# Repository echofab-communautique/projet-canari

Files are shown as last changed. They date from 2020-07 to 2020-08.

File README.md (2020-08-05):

# projet-canari
captation citoyenne de données sur la qualité de l’air

canari

_Les bien commun de l’environnement_  
Communautique, en tant qu’organisme de démocratisation des technologies, souhaite créer un espace de conversation sur les données ouvertes, les capteurs et leurs usages. Le Projet Canari vise à développer des contenus de formation pratiques de création et d’appropriation des données locales pour la résolution d’enjeux urbains, comme la qualité de l’air.  

(http://www.youtube.com/watch?v=Zew5YFMf60w "Click to see our trailer")

## Le processus en bref:  
Utiliser les Fab Labs (espaces citoyens) pour prendre actions sur le changement climatique

1- Une marche de sensibilisation de son environnement  “Rendre l’invisible visible”  
2- Construction d’un outils permettant de capter par le citoyen  
  2.1- Introduction au fab lab et technologie de fabrication numérique  
3- Installation et captation (contribution ou création de data citoyenne)  
4- Retour et analyse des données captée  
5- Recherche de solutions  
6- Processus itératif en amélioration continue  

## Besoins  
La mobilisation des habitants sur les questions des capteurs, des données et de l’environnement (qualité de l’air) permettra de développer la littératie des données.
Le Projet Canari souhaite ainsi contribuer à :
* Développer la littératie des données
* Connecter le citoyen aux notions de changement climatique (rendre visible la dimension invisible des changements climatiques dans des ancrages locaux). Les changements climatiques ont trop souvent quelque chose d’abstrait, mais pour beaucoup de citoyens, avoir un air respirable dans notre ville est la priorité environnementale.
* Valoriser le savoir scientifique en recueillant les données par une méthodologie de recherche  

Afin d'accompagner les citoyen.nes dans leur démarche de captation, une escouade des données («data squad») - composée de personnes aux compétences complémentaires (techniques, anthropolo/ethnologique, communication/animation) - sera formée afin d'animer et de soutenir la participation au projet. Cette petite équipe terrain joue un rôle crucial de médiation «socio-technique» - en proximité avec les participant.e.s du projet : elle facilite l'appropriation de l'instrumentation, identifie des opportunités d'intervention, soutient les processus de collecte, d'analyse et d'interprétation des données. L'escouade est également responsable de la mutualisation des informations collectées (en respectant les cadres et les règles de confidentialité et de protection des renseignements personnels), dans la perspective de constitution d'un commun des données citoyennes sur l'environnement.  

Le temps de la data squad :  
* ils accompagnent le lancement du projet
* ils accompagnent la fabrication au Fab Lab des capteurs
* accompagnent hebdomadaire/ visite – formation des capteurs et accompagnement virtuel/ à travers la plateforme

Les habitants participants au projet s’engage:
* sur une période de deux mois via une charte d’engagement sur l'impératif de protection des données personnelles et de la législation
* à avoir à disposition un kit de mesure contenant un capteur de mesure de particules fines et de la documentation sur le sujet
* à évaluer son exposition personnelle aux particules fines présentes dans l'air qui nous entoure
* à réfléchir aux comportements que l'on peut adopter pour améliorer son air extérieur
* à se sensibiliser et sensibiliser les autres en en parlant autour de soi
* à participer à des animations avec des experts

## Mise en contexte, historique du projet
Nous assistons actuellement à une transformation profonde à l’échelle mondiale qui est alimentée par la technologie et les médias numériques, et stimulée par les données et les flux d’information. Cette transformation constitue un potentiel énorme pour renforcer la transparence, la redevabilité , l’efficience, l’agilité et l’efficacité des gouvernements ainsi que des organisations de la société civile et du secteur privé et pour appuyer la conception, la mise en œuvre et l’évaluation d’objectifs de développement durable à l’échelle mondiale. Les données ouvertes sont au cœur de ce mouvement mondial. Cependant, la formation à l’usage des données est un préalable essentiel et trop souvent négligé pour un usage plus large des données.

La création et l’usage de données ouvertes offrant un beau potentiel de s'approprier sa Ville, Communautique en tant qu’organisme de formation continue, engagé dans le mouvement mondial des Fab City, propose le Projet Canari. Articulant depuis maintenant plusieurs années des activités autour des laboratoires de fabrication numérique et la mise en place d’un réseau de fabrication numérique au Québec, le projet permettra de démontrer le rôle des Fab Labs :
* dans la gestion des compétences et des connaissances à l’échelle individuelle et collective
* comme espace de médiation entre les habitants et les enjeux de société
* à faciliter la participation citoyenne et la mise en place d’une communauté de pratique
* pour envisager la technologie comme outil pour façonner le territoire différemment
* pour favoriser le développement inclusif de solutions et l’innovation

Le canari sentinelle

“Au XIXe siècle, alors que l’exploitation des mines de charbon battait son plein, il était fréquent de retrouver, au fond des mines, un canari. Très sensible aux émanations de gaz toxiques, impossibles à détecter pour les hommes ne bénéficiant pas des équipements modernes, le petit oiseau jaune servait d’outil de référence. Ainsi, lorsqu’il mourait ou s’évanouissait, les mineurs se dépêchaient de sortir de la mine afin d’éviter une explosion ou une intoxication imminentes.” Source : Histoires oubliées http://www.histoiresoubliees.ca/article/la-mine-federale/les-canaris-dans-les-mines-de-charbon

## Objectif général
Le Projet Canari contribue à développer la littératie numérique et environnementale et à rendre les citoyens acteurs de la mesure de la qualité de l’air en les accompagnant à fabriquer des micro-capteurs.  
Par la formation aux enjeux de la production et de l’utilisation des données ouvertes, il outillera concrètement les citoyens, dont des nouveaux arrivants, en améliorant leurs compétences et connaissances pour utiliser l’Internet et les données de manière signifiante et sécuritaire.  

## Nomenclature (BOM)

[BOM.pdf](https://github.com/echofab-communautique/projet-canari/files/5006105/BOM.pdf)

Elements:
1x Jumper Cable
1x Cable USB
1x Arduino Nano
1x Ecran OLED
1x Senseur PM2.5
1x PCB
1x Résistance 150 Ohms
1x Cap 220 uF
2x Terminal Block 5mm / 3pos
2x Terminal Block 5mm / 2pos

Autres:
Fil à pêche (30cm)
Impressions 3D (coeur, set de press pin -bec & tail miroir) => voir dossier 1_3Dprint
Découpe laser du profil extérieur => voir dossier 3_Laser
Découpe vinyle des ailes => voir dossier 2_Vinyle
Tournevis

Pour plus de détails, vous pouvez télécharger et consulter le fichier BOM.pdf

## Réalisation  

Les fichiers de production sont téléchargeables dans les dossiers de ce projet:  
* 1_3Dprint  
* 2_Vinyle  
* 3_Laser  
* 4_CNC_PCB
* 5_Code

## Montage  

Tutoriel vidéo:  
(http://www.youtube.com/watch?v=UymSCfy-eLw "")

Tutoriel PDF:
[Guide Atelier canariF2.pdf](https://github.com/echofab-communautique/projet-canari/files/5026637/Guide.Atelier.canariF2.pdf)

Quelques photos:

production3
production

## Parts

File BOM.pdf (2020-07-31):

Canari | Min
Éléments | Quantité/canari $/unité | $ totale

Temps de prod.
/unité
Jumper Cable | 4Xf-f 4Xm-f | 389 | NA | https://www.amazon.ca/-/fr/gp/product/B08151TQHG/ref=ppx_yo_dt_b_asin_image_o00_s00?ie=UTF8&psc=1
Cable USB: | 1 | 384,02 | NA | https://www.primecables.ca/fr/shopping_cart Arduino Nano: (pousser le code) | 1 | 566,03 | 1 https://www.aliexpress.com/item/33011803738.html?spm=a2g0s.9042311.0.0.143a4c4do47f8p
Ecran OLED: | 1 | 408,78 | NA | https://www.aliexpress.com/item/4001066065622.html?spm=a2g0s.9042311.0.0.143a4c4do47f8p
Senseur PM2.5 ( + souder fil) | 1 | 1055,01 | 1 https://www.aliexpress.com/item/32730375549.html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,searchweb201602_,searchweb201603_'
PCB | 1 | 58 | 2 https://cart.jlcpcb.com/quote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
Resistance 150 Omhs | 1 | 2,78 | NA | https://www.digikey.ca/en/products/detail/koa-speer-electronics-inc/RK73H2BTTD1500F/10237637
Cap 220 uF | 1 | 18,79 | NA | https://www.digikey.ca/en/products/detail/illinois-capacitor/227CKE016M/5411711
Terminal Block 5mm / 3pos | 2 | NA
Terminal Block 5mm / 2pos | 2 | NA
Sous Total | 16,01338889 | 2882,41
Fil à pêche (30 cm) | 1 Coeur, tient électronique, 3D print | 1 | 160 Set de press pin (bec & tail miroir) 3D print | 4 | 26 Profil extérieur Laser | 2 | 3 Ailes mirroir Vinyle | 2 | 1 Tournevis | 1

3
TOTAL | 19,01338889

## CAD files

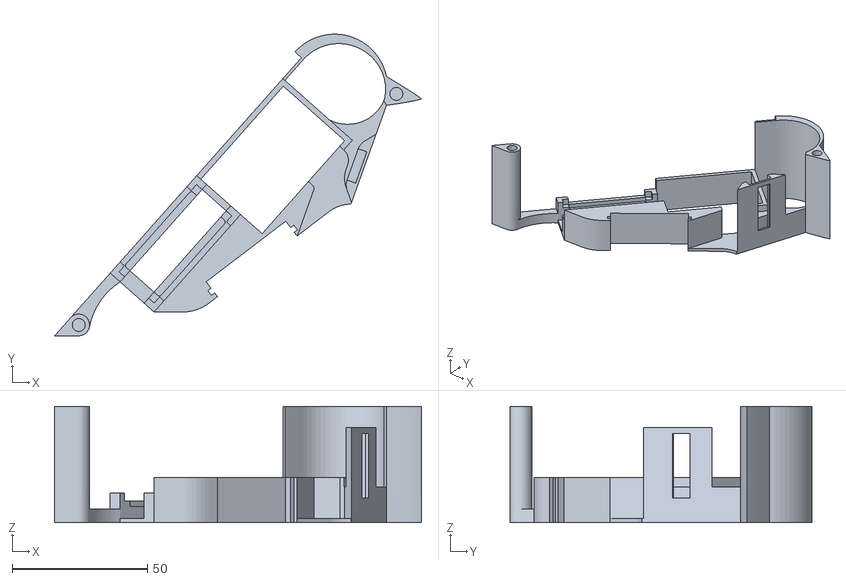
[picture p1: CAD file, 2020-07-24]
1_3D print/originale/organes 3D PRINT woodbending.stl
135.8 x 111.6 x 43.0

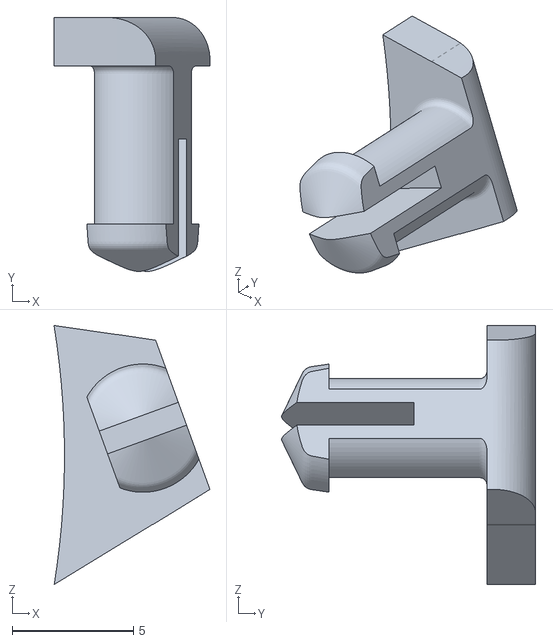
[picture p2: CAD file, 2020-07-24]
1_3D print/originale/pinB1.stl
6.43 x 10.5 x 10.7

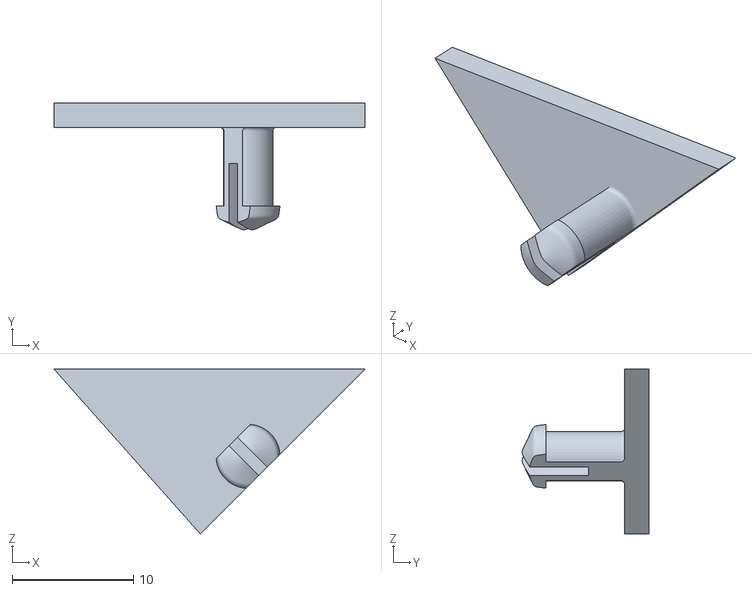
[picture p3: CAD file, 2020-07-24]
1_3D print/originale/pinT2.stl
25.7 x 10.5 x 13.6

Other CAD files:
1_3D print/originale/pinB2.stl
1_3D print/originale/pinT1.stl

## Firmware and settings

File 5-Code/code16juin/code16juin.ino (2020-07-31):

// Choose program options.
//#define PRINT_RAW_DATA
#define USE_AVG

// Arduino pin numbers.
const int sharpLEDPin = 7;   // Arduino digital pin 7 connect to sensor LED.
const int sharpVoPin = A3;   // Arduino analog pin 5 connect to sensor Vo.



#include <Wire.h>
#include <Adafruit_GFX.h>
#include <Adafruit_SSD1306.h>


#define SCREEN_WIDTH 128
#define SCREEN_HEIGHT 32

Adafruit_SSD1306 display(SCREEN_WIDTH, SCREEN_HEIGHT, &Wire, -1);


// For averaging last N raw voltage readings.
#ifdef USE_AVG
#define N 100
static unsigned long VoRawTotal = 0;
static int VoRawCount = 0;
#endif // USE_AVG

// Set the typical output voltage in Volts when there is zero dust.
static float Voc = 0.6;

// Use the typical sensitivity in units of V per 100ug/m3.
const float K = 0.5;

/////////////////////////////////////////////////////////////////////////////

// Helper functions to print a data value to the serial monitor.
void printValue(String text, unsigned int value, bool isLast = false) {
  Serial.print(text);
  Serial.print("=");
  Serial.print(value);
  if (!isLast) {
    Serial.print(", ");
  }
}
void printFValue(String text, float value, String units, bool isLast = false) {
  Serial.print(text);
  Serial.print("=");
  Serial.print(value);
  Serial.print(units);
  if (!isLast) {
    Serial.print(", ");
  }
}

/////////////////////////////////////////////////////////////////////////////

// Arduino setup function.
void setup() {

  if (!display.begin(SSD1306_SWITCHCAPVCC, 0x3C)) {
    Serial.println(F("SSD1306 allocation failed"));
  }
  // Set LED pin for output.
  pinMode(sharpLEDPin, OUTPUT);

  // Start the hardware serial port for the serial monitor.
  Serial.begin(9600);

  // Wait two seconds for startup.
  delay(2000);
  Serial.println("");
  Serial.println("GP2Y1014AU0F Demo");
  Serial.println("=================");
}

// Arduino main loop.
void loop() {
  // Turn on the dust sensor LED by setting digital pin LOW.
  digitalWrite(sharpLEDPin, LOW);

  // Wait 0.28ms before taking a reading of the output voltage as per spec.
  delayMicroseconds(280);

  // Record the output voltage. This operation takes around 100 microseconds.
  int VoRaw = analogRead(sharpVoPin);

  // Turn the dust sensor LED off by setting digital pin HIGH.
  digitalWrite(sharpLEDPin, HIGH);

  // Wait for remainder of the 10ms cycle = 10000 - 280 - 100 microseconds.
  delayMicroseconds(9620);

  // Print raw voltage value (number from 0 to 1023).
#ifdef PRINT_RAW_DATA
  printValue("VoRaw", VoRaw, true);
  Serial.println("");
#endif // PRINT_RAW_DATA

  // Use averaging if needed.
  float Vo = VoRaw;
#ifdef USE_AVG
  VoRawTotal += VoRaw;
  VoRawCount++;
  if ( VoRawCount >= N ) {
    Vo = 1.0 * VoRawTotal / N;
    VoRawCount = 0;
    VoRawTotal = 0;
  } else {
    return;
  }
#endif // USE_AVG

  // Compute the output voltage in Volts.
  Vo = Vo / 1024.0 * 5.0;
  printFValue("Vo", Vo * 1000.0, "mV");

  // Convert to Dust Density in units of ug/m3.
  float dV = Vo - Voc;
  if ( dV < 0 ) {
    dV = 0;
    Voc = Vo;
  }
  float dustDensity = dV / K * 100.0;
  printFValue("DustDensity", dustDensity, "ug/m3", true);
  Serial.println("");

  if ((dustDensity >= 0) && (dustDensity <= 12)) {
    Serial.println("- Good air -");
    display.clearDisplay();                  // Efface tout ce qui ce trouve a l'écran.
    display.setTextSize(1);                  // Ajuste la dimension du texte qui sera affiché.
    display.setTextColor(WHITE);             // Ajuste la couleur du texte qui sera affiché (Dois rester blanc.
    display.setCursor(30, 10);                // Ajuste la position du texte sur l'écran.
    display.print(dustDensity);            // Le texte qui sera imprimé a l'écran
    display.print(" Good air");
    display.display();                       // Permet a l'écran de changer ses caracthères.
  } else if ((dustDensity >= 13) && (dustDensity <= 35)) {
    Serial.println("- Moderate air -");
    display.clearDisplay();                  // Efface tout ce qui ce trouve a l'écran.
    display.setTextSize(1);                  // Ajuste la dimension du texte qui sera affiché.
    display.setTextColor(WHITE);             // Ajuste la couleur du texte qui sera affiché (Dois rester blanc.
    display.setCursor(30, 10);                // Ajuste la position du texte sur l'écran.
    display.print(dustDensity);            // Le texte qui sera imprimé a l'écran
    display.print(" Moyenne");
    display.display();
  } else if ((dustDensity >= 36) && (dustDensity <= 55)) {
    Serial.println("- Unhealthy for sensitive groupe -");
    display.clearDisplay();                  // Efface tout ce qui ce trouve a l'écran.
    display.setTextSize(1);                  // Ajuste la dimension du texte qui sera affiché.
    display.setTextColor(WHITE);             // Ajuste la couleur du texte qui sera affiché (Dois rester blanc.
    display.setCursor(30, 10);                // Ajuste la position du texte sur l'écran.
    display.print(dustDensity);            // Le texte qui sera imprimé a l'écran
    display.print(" Unhealthy");
    display.display();
  } else if ((dustDensity >= 56) && (dustDensity <= 150)) {
    Serial.println("- bad -");
    display.clearDisplay();                  // Efface tout ce qui ce trouve a l'écran.
    display.setTextSize(1);                  // Ajuste la dimension du texte qui sera affiché.
    display.setTextColor(WHITE);             // Ajuste la couleur du texte qui sera affiché (Dois rester blanc.
    display.setCursor(30, 10);                // Ajuste la position du texte sur l'écran.
    display.print(dustDensity);            // Le texte qui sera imprimé a l'écran
    display.print(" Unhealthy");
    display.display();
  } else if ((dustDensity >= 151) && (dustDensity <= 250)) {
    Serial.println("- Very unhealty -");
    display.clearDisplay();                  // Efface tout ce qui ce trouve a l'écran.
    display.setTextSize(1);                  // Ajuste la dimension du texte qui sera affiché.
    display.setTextColor(WHITE);             // Ajuste la couleur du texte qui sera affiché (Dois rester blanc.
    display.setCursor(30, 10);                // Ajuste la position du texte sur l'écran.
    display.print(dustDensity);            // Le texte qui sera imprimé a l'écran
    display.print(" Dangerous");
    display.display();
  } else {
    Serial.println("- You will die soon-");
    display.clearDisplay();                  // Efface tout ce qui ce trouve a l'écran.
    display.setTextSize(1);                  // Ajuste la dimension du texte qui sera affiché.
    display.setTextColor(WHITE);             // Ajuste la couleur du texte qui sera affiché (Dois rester blanc.
    display.setCursor(30, 10);                // Ajuste la position du texte sur l'écran.
    display.print(dustDensity);            // Le texte qui sera imprimé a l'écran
    display.print(" RUN!");
    display.display();
  }



} // END PROGRAM
